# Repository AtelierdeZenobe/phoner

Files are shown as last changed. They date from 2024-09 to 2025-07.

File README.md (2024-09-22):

# Phoner [WORK IN PROGRESS]
Automate calls using sim800l module and [DFRobot Beetle_ESP32_C6](https://wiki.dfrobot.com/SKU_DFR1117_Beetle_ESP32_C6)

## Next steps
- LEDs
- 3D casing design

## Hardware setup
TODO pin diagram  
The sim800l module requires precise 3.7 voltage. [LIR2032H](https://www.eemb.com/product-11)

## Environment setup
1. Follow the [First Time Use](https://wiki.dfrobot.com/SKU_DFR1117_Beetle_ESP32_C6#target_7) to make the board available to arduino IDE
2. For serial monitor: Tools > USB CDC On Boot > Enabled

## Doc
[Sim800l arduino tutorial](https://lastminuteengineers.com/sim800l-gsm-module-arduino-tutorial/)

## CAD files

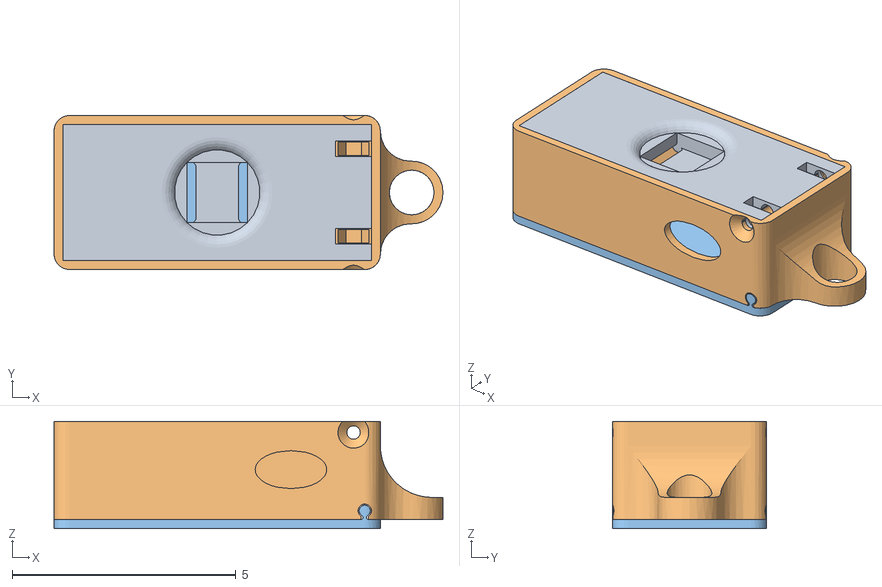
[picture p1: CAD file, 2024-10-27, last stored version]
3D/Phoner_Assembly v3.obj
8.70 x 3.45 x 2.40

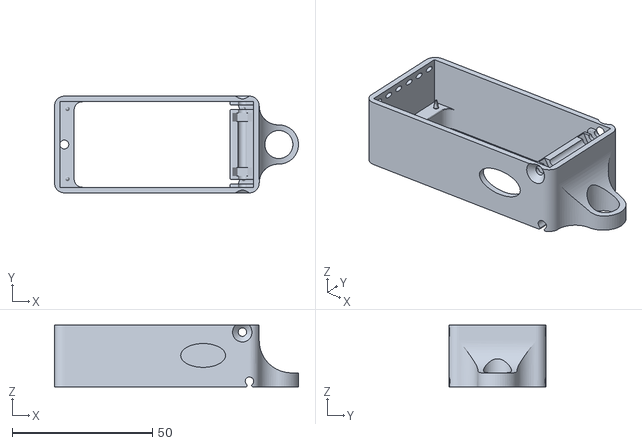
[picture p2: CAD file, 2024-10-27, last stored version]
3D/Phonerv2 v16.stl
87.0 x 34.5 x 22.0

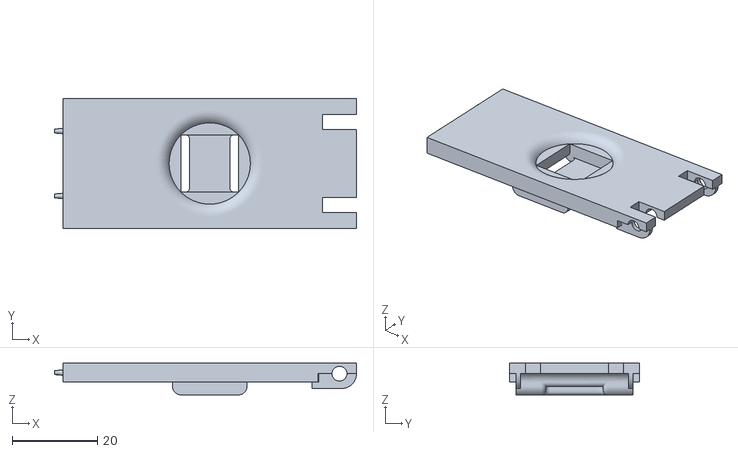
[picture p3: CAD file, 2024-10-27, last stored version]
3D/PhonerTop v6.stl
71.0 x 30.5 x 7.50

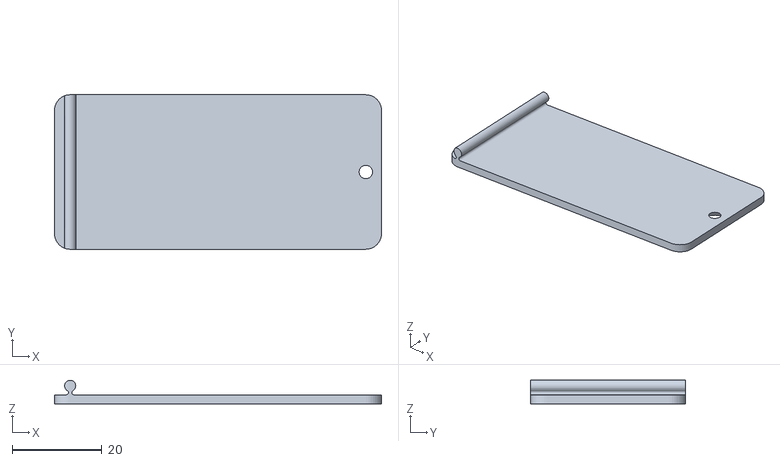
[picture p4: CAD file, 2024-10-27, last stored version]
3D/PhonerBot v4.stl
73.0 x 34.5 x 5.25

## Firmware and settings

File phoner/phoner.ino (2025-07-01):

// Tests done
// - check deepleep -> update some code, lib
// - check SIM in sleep -> if do not define CALL_FRED, that's ok !!
//                         if        define CALL_FRED, that's not ok !! I may get the call but SIM800L does not sleep after
// It's so weird, not stable from test to test
// Definetely need to check answer from SIM, retry if not the expected answer ?
// Ok it works by adjusting delays !

// RST pin is HIGH -> SIM on
// DTR pin is LOW  -> com' UART active (used for sleep mode 1)
// use Sleep mode 2
// put some delay when sending AT CFUN and CSCLK to make sure I got an OK from sim

/// Wifi
#include <WiFi.h>
#include <HTTPClient.h>
#include "info.h"
/**
Current directory should contain "info.h" defining:
struct WifiIds
{
  const char* ssid;
  const char* password;
};
constexpr WifiIds wifiIds[] =
{
  {"SSID1", "PWD1"}, // Maison parents
  {"SSID2", "PWD2"}, // Maison Loncin
};

const char* botToken, the telegram bot token (@BotFather)
const char* chat_id, the telegram chat id (@userinfobot)
*/

/// Deepsleep
#include "driver/rtc_io.h" // see https://randomnerdtutorials.com/esp32-deep-sleep-arduino-ide-wake-up-sources/
/// Sim800l comm
#include <HardwareSerial.h>

const char* PHONE_NUMBER = "+32498341934";
//const char* PHONE_NUMBER = "+32475896931";

#define USE_SIMPLE_DELAY false // set "false" for the new code for ATCommand, otherwise, set "true" to  use OLD CODE with SIMPLE DELAY
#define DELAY_WAIT_SIM 5000   
#define SHORT_DELAY_WAIT_SIM 200
#define TIMEOUT_SIM 15000 // used if USE_SIMPLE_DELAY = false

#define SLEEP_MODE 2 // 1 (using DTR pin) or 2

const int RX_PIN = 17; // ESP RX (vert)
const int TX_PIN = 16; // ESP TX (jaune)

/// Button
#define BTN_GPIO GPIO_NUM_6 // PIN 6/D12 = LP GPIO for wake up ESP32

#define LED_R GPIO_NUM_20
#define LED_G GPIO_NUM_19
const int LED_B = 0xFF; // Not connected
const int RST_GPIO = 0xFF; // Not connected
const int DTR_GPIO = 0xFF; // Not connected


HardwareSerial sim800l(1); // RX, TX pins defined above

/// Battery
const int VBAT_PIN = 0; // IO0 through a res bridge (VBAT--1M--IO0--1M//100nF--GND) as in SCH
const float VREF = 3.3;

/// On-board led
const int led = 15;

/// Setup logic
RTC_DATA_ATTR int bootCount = 0;

constexpr int MAX_WIFI_TENTATIVES = 50;

enum OPERATION_RESULT
{
  ONGOING,
  DONE,
  TIMEOUT,
  WRONG_ANSWER
};

enum class SM : int
{
  INIT = 0,
  PRESSED,
  WIFI_ATTEMPT,
  GSM_ATTEMPT,
  SUCCESS,
  FAIL
};

OPERATION_RESULT sendATCommand(HardwareSerial &serial, const char *message,const char *command, const char *expectedResponse, unsigned long timeout, bool use_delay, unsigned long delay_value);
bool ConnectToWifi();
bool setState(SM next_state, SM& current_state);

void setup()
{ 
  /// On-board led
  pinMode(led, OUTPUT);
  pinMode(LED_R, OUTPUT);
  pinMode(LED_G, OUTPUT);
  
  /// Btn
  pinMode(BTN_GPIO, INPUT);          // I made it as a pullup button, so use PULLDOWN internal resistor with rtc functions (see after call deep_sleep)
                                     // change input arg of deep sleep function esp_sleep_enable_ext1_wakeup accordingly
                                     // it seems that a pullup button is better, the wake up condition on HIGH input is better
  
  /// Battery check
  analogReadResolution(12);
  //analogSetAttenuation(ADC_6db); //ESP32-C6 datasheet: 0mv - 1900mV
  // Best to avoid edges => Going full range with "biggest error"
  analogSetAttenuation(ADC_11db);  //ESP32-C6 datasheet: 0mv - 3300 mV
  pinMode(VBAT_PIN, INPUT);

  // setup SIM800L pin digital level
  // digitalWrite(DTR_GPIO,LOW);
  // digitalWrite(RST_GPIO,HIGH);
  // delay(100);

  // Setup Serial communications
  Serial.begin(9600); // Serial monitor comm
  Serial.write("Serial initialized\n");
  Serial.write("Use Phoner Board v1.2 \n");

  // Setup sim800l module
  Serial.write("Initializing SIM800L ...");
  sim800l.begin(9600, SERIAL_8N1, RX_PIN, TX_PIN); // Works with HardwareSerial(1)
  Serial.write("done\n");
  delay(1000); // need a delay here
}

void loop()
{
  SM sm = SM::INIT;

  Serial.print("Bootcount = ");
  Serial.println(bootCount);
  // blink(500,bootCount); // for debug purpose
  // blinkForBattery();

  if(bootCount++ == 0)
  {
    start_sim800L();
    sleep_sim800L();
  }
  else
  {
    setState(SM::PRESSED, sm);
    SM next_state = ConnectToWifi() && false ? SM::WIFI_ATTEMPT : SM::GSM_ATTEMPT;
    setState(next_state, sm);
    if (sm == SM::WIFI_ATTEMPT)
    {
      HTTPClient http;
      String message = "PHONER_EMERGENCY";
      String url = String("https://api.telegram.org/bot") + botToken +
                  "/sendMessage?chat_id=" + chat_id +
                  "&text=" + message;
      http.begin(url);
      int httpCode = http.GET();
      Serial.println("HTTP Status: " + String(httpCode));
      if (httpCode != 200)
      {
        setState(SM::GSM_ATTEMPT, sm);
        String response = http.getString();
        Serial.println("Telegram Error: " + response);
      }
      else
      {
        setState(SM::SUCCESS, sm);
      }
      http.end();
    }

    if(sm == SM::GSM_ATTEMPT)
    {
      Serial.println("Could not connect to wifi, trying GSM");
      wake_up_sim800L();
      if(!call())
      {
        setState(SM::FAIL, sm);
      }
      else
      {
        setState(SM::SUCCESS, sm);
      }
      sleep_sim800L();
    }
    else
    {
      Serial.print("SM state: ");
      Serial.println(static_cast<int>(sm));
    }
  }
  delay(2000); // Easier to re-flash
  blinkForBattery(); // check battery before sleep
  sleep_esp32();
  Serial.println("This will never be printed");
}

// ------------------------------------------------------------- //
// ESP32 functions
// ------------------------------------------------------------- //
// sleep_esp32()

bool setState(SM next_state, SM& current_state)
{
  // TODO: allowed transitions
  bool result = false;
  switch(next_state)
  {
    case SM::INIT:
    {

    }
    case SM::PRESSED:
    {
      blink_RGB(500, 1, HIGH, LOW, LOW); //R
      blink_RGB(500, 1, LOW, HIGH, LOW); //G
      digitalWrite(LED_R, HIGH);
      digitalWrite(LED_G, HIGH);
      //blink_RGB(500, 1, HIGH, HIGH, LOW); //Orange ?
      result = true;
      break;
    }
    case SM::WIFI_ATTEMPT: // Orange
    {
      blink_RGB(500, 3, HIGH, HIGH, LOW); //Orange ?
      digitalWrite(LED_R, HIGH);
      digitalWrite(LED_G, HIGH);
      result = true;
      break;
    }
    case SM::GSM_ATTEMPT: // Blink red then Orange
    {
      blink_RGB(500, 3, HIGH, LOW, LOW);
      digitalWrite(LED_R, HIGH);
      digitalWrite(LED_G, HIGH);
      result = true;
      break;
    }
    case SM::SUCCESS: // GREEN
    {
      digitalWrite(LED_R, LOW);
      digitalWrite(LED_G, HIGH);
      result = true;
      break;
    }
    case SM::FAIL: // RED
    {
      digitalWrite(LED_R, HIGH);
      digitalWrite(LED_G, LOW);
      result = true;
      break;
    }
    default:
    {
      Serial.println("Default state should never happen");
    }
  }

  if(result)
  {
    Serial.print("Transition : "); Serial.print(static_cast<int>(current_state)); Serial.print(" -> "); Serial.print(static_cast<int>(next_state));
    current_state = next_state;
  }
  else
  {
    Serial.print("Incorrect transition : "); Serial.print(static_cast<int>(current_state)); Serial.print(" -> "); Serial.print(static_cast<int>(next_state));
  }
  return result;
}

bool ConnectToWifi()
{
  for (int i = 0; i < N_WIFI; ++i) 
  {
    int tentative = 0;
    const char* ssid = wifiIds[i].ssid;
    const char* password = wifiIds[i].password;

    Serial.println("Attempting to connect to wifi:");
    Serial.print("\t"); Serial.println(ssid);
    Serial.print("\t"); Serial.println(password);

    WiFi.begin(ssid, password);

    while ( (WiFi.status() != WL_CONNECTED) && (tentative++ < MAX_WIFI_TENTATIVES) )
    {
      delay(500);
      Serial.print(".");
    };
    Serial.println("");

    if(WiFi.status() == WL_CONNECTED)
    {
      Serial.println("\nWiFi connected");
      return true;
    }

    WiFi.disconnect(true);  // true = erase old config
    delay(100); // give some time to cleanly disconnect
  }
  return false;
}

void sleep_esp32()
{
  // TODO: use ANY_LOW if pull-up
  // https://randomnerdtutorials.com/esp32-deep-sleep-arduino-ide-wake-up-sources/
  esp_sleep_enable_ext1_wakeup((1ULL << BTN_GPIO), ESP_EXT1_WAKEUP_ANY_HIGH);
  // esp_sleep_enable_ext0_wakeup(BTN_GPIO, 1); // wake up if BTN pressed 
                                                // idt does not work ?? https://github.com/espressif/esp-idf/issues/11932
  rtc_gpio_pulldown_en(BTN_GPIO);  // GPIO6 is tie to GND in order to wake up in HIGH
  rtc_gpio_pullup_dis(BTN_GPIO);   // Disable PULL_UP in order to allow it to wakeup on HIGH
  // reminder : COM port is disabled, so board does show disconnected in IDE
  esp_deep_sleep_start();
}

// ------------------------------------------------------------- //
// SIM800L functions
// ------------------------------------------------------------- //
// sendATCommand()
// start_sim800L()
// reset_sim800L()
// sleep_sim800L()
// wake_up_sim800L()
// call()

// Send and check AT Commeand
// use : sendATCommand(sim800l,"Message for serial Monitor","AT","OK",DELAY_SLEEP_SIM)
OPERATION_RESULT sendATCommand(HardwareSerial &serialSIM, const char *message,const char *command, const char *expectedResponse, unsigned long timeout = TIMEOUT_SIM, bool use_delay = USE_SIMPLE_DELAY, unsigned long delay_value = DELAY_WAIT_SIM)
{
  OPERATION_RESULT result = OPERATION_RESULT::ONGOING;
  serialSIM.println(command);
  if (use_delay)
  {
    updateSerial();
    delay(delay_value);
    result = OPERATION_RESULT::DONE;
  }
  else
  {
    unsigned long startTime = millis();
    unsigned long elapsedTime = 0;
    String response = "";

    while ( result==OPERATION_RESULT::ONGOING )
    {
      elapsedTime =  millis() - startTime;
      if( elapsedTime > timeout )
      {
        result = OPERATION_RESULT::TIMEOUT;
      }
      while (serialSIM.available() && result==OPERATION_RESULT::ONGOING)
      {
        char c = serialSIM.read();
        response += c;
        // Vérifiez si la réponse attendue est contenue
        if (response.indexOf(expectedResponse) != -1)
        {
          result = OPERATION_RESULT::DONE;
        }
      }
      //delay(1); // it is ok because baudrate is set to 9600x
    }

    switch(result)
    {
      case OPERATION_RESULT::DONE:
      {
        Serial.println(String(message) + " Command " + String(command) + " success");
        Serial.println(response);
        Serial.println(elapsedTime);
        break;
      }
      case OPERATION_RESULT::ONGOING:
      {
        Serial.println(String(message) + " Command " + String(command) + " ONGOING");
        Serial.println(response);
        break;
      }
      case OPERATION_RESULT::TIMEOUT:
      {
        Serial.println(String(message) + " Command " + String(command) + " TIMEOUT");
        Serial.println(response);
        Serial.println(elapsedTime);
        break;
      }
      case OPERATION_RESULT::WRONG_ANSWER:
      {
        Serial.println(String(message) + " Command " + String(command) + " WRONG ANSWER");
        Serial.println(response);
        break;
      }
      default:
      {
        Serial.println(String(message) + " Command " + String(command) + " DEFAULT");
        Serial.println(response);
        break;
      }
    }     
    return result;
  }
}

void start_sim800L()
{
  wake_up_sim800L();
  sendATCommand(sim800l,"Starting handshake...","AT","OK"); // Starting handshake
  sendATCommand(sim800l,"Signal quality test...","AT+CSQ","OK"); //Signal quality test, value range is 0-31 , 31 is the best
  sendATCommand(sim800l,"Reading SIM information...","AT+CCID","OK"); //Read SIM information to confirm whether the SIM is plugged
  //sendATCommand(sim800l,"Selecting mobile operator...","AT+COPS=0,2","OK",TIMEOUT_SIM,USE_SIMPLE_DELAY,SHORT_DELAY_WAIT_SIM); // select the mobile network operator| AT+COPS=<mode>(0 for auto),<format>(2 for numeric),<oper>,<AcT>
  // there is an error here, is it worth sending this command ? So comment it
  sendATCommand(sim800l,"Checking network status...","AT+CREG?","OK"); //check the network registration status. Will answer +CREG: <n>,<stat>
  sendATCommand(sim800l,"Querying battery status...","AT+CBC","OK"); // Querry battery status
  sendATCommand(sim800l,"Enabling CLC...","AT+CLCC=0","OK"); // Don't send AT+CLCC async
}
void reset_sim800L()
{
  digitalWrite(RST_GPIO,HIGH);
  delay(200);
  digitalWrite(RST_GPIO,LOW); // put this pin LOW for (at least) 100ms for a hard reset
  delay(200);
  digitalWrite(RST_GPIO,HIGH);
  delay(200);
}
// Sleep mode 2 : https://www.raviyp.com/223-sim900-sim800-sleep-mode-at-commands/
// RF OFF : datasheet page 26, section 4.3
void sleep_sim800L()
{
  Serial.println("");
  Serial.println("Going to sleep now");
  while(sendATCommand(sim800l,"Set RF off","AT+CFUN=4","OK") != OPERATION_RESULT::DONE){
    delay(SHORT_DELAY_WAIT_SIM);
  } // wait for the OK response, it may take a while to get the answer;
  delay(DELAY_WAIT_SIM); // should reply within 10 sec max according to AT CFUN page 96
  if (SLEEP_MODE == 1)
  {
    while(sendATCommand(sim800l,"Set sleep mode 1","AT+CSCLK=1","OK") != OPERATION_RESULT::DONE){
      delay(SHORT_DELAY_WAIT_SIM);
    } // wait for the OK response, it may take a while to get the answer;
    delay(100);
    digitalWrite(DTR_GPIO,HIGH); // put high for sleep mode
    delay(100);
  }
  else if (SLEEP_MODE == 2)
  {
    while(sendATCommand(sim800l,"Set sleep mode 2","AT+CSCLK=2","OK") != OPERATION_RESULT::DONE){
      delay(SHORT_DELAY_WAIT_SIM);
    } // wait for the OK response, it may take a while to get the answer;
    delay(DELAY_WAIT_SIM*2); // wait for at least 5s without UART, on air or IO INTR
  }
  else 
  {
    // no SLEEP mode
  }
}

void wake_up_sim800L()
{
  Serial.println("Wake up SIM800L");
  sim800l.println("AT"); // dummy data, wait no response, so do not use sendATCommand
  delay(200); // datasheet AT command page 153, note 2 : apply a delay of (at least) 100ms between dummy/waking data and AT command
  Serial.println("Disable sleep mode");
  if (SLEEP_MODE == 1)
  {
    digitalWrite(DTR_GPIO,LOW);
    delay(100); // UART should be ready after 50ms
  }
  else if (SLEEP_MODE == 2)
  {
    sendATCommand(sim800l,"Wake up module SIM","AT+CSCLK=0","OK");
    delay(DELAY_WAIT_SIM); // wait for at least 5s without UART, on air or IO INTR
  }
  else 
  {
    // no SLEEP mode
  }
  sendATCommand(sim800l,"Wake up RF","AT+CFUN=1","OK");
  delay(DELAY_WAIT_SIM); // wait for a few seconds to let RF be ready
}

bool call()
{
  Serial.println("Who do you call ?");
  // CALL

  OPERATION_RESULT call_success;
  OPERATION_RESULT hang_success;

  if (strlen(PHONE_NUMBER) >= 9)
  {
    call_success=sendATCommand(sim800l,"Calling...",(String("ATD") + PHONE_NUMBER + ";").c_str(),"OK",TIMEOUT_SIM,USE_SIMPLE_DELAY,SHORT_DELAY_WAIT_SIM);
  }
  else
  {
    Serial.write("Size of phone number < 9 => Fake call...\n");
    call_success=OPERATION_RESULT::DONE; 
  }

  Serial.write("Waiting for answer\n");
  long timeout = millis() + 20*1000;
  String answer;
  while (millis() < timeout)
  {
    auto callStatus = sendATCommand(sim800l, "Checking call status...", "AT+CLCC", "+CLCC: 1,0,0,0,0,", 500);
    if(callStatus == OPERATION_RESULT::DONE)
    {
      Serial.println("Connected");
    }
    else
    {
      Serial.println(".");
    }
    /*
    if (sim800l.available())
    {
      
      
      char c = sim800l.read();
      //Serial.print(c);  // Forward response to serial monitor
      answer += c;
      if(c == '\n')
      {
        //Serial.print("EOL detected. Checking answer\n");
        Serial.print(answer);
        if(answer.substring(0,5)=="+CLCC")
        {
          Serial.print("CLCC detected\n");
        }
        answer = "";
      }
      
    }
    */
  }
  /*
  for (int n_loop=0;n_loop<20;n_loop++)
  {
    delay(1000); // wait
    Serial.print(".");
  }
  */
  Serial.println("");
  // better to wait for a reply or a connection beforing hanging up ??
  hang_success=sendATCommand(sim800l,"Hanging up...","ATH","OK");
  // here, check if call and/or hanging are true
  if ( (hang_success != OPERATION_RESULT::DONE) && (call_success != OPERATION_RESULT::DONE)) // a problem occurred -> blink or restart call ?
    return false;
  else
    return true;
}

// ------------------------------------------------------------- //
// Misc functions
// ------------------------------------------------------------- //

void updateSerial()
{
  delay(500); // wait for any incoming data
  while (Serial.available()) 
  {
    sim800l.write(Serial.read());//Forward what Serial received to Software Serial Port
  }
  while(sim800l.available()) 
  {
    Serial.write(sim800l.read());//Forward what Software Serial received to Serial Port
  }
}

// blink N times the LED with a period of 2*millis
void blink(const int millis,int N)
{
  for (int i=0;i<N;i++)
  {
    digitalWrite(led, LOW);
    delay(millis);
    digitalWrite(led, HIGH);
    delay(millis);
    digitalWrite(led, LOW);
  }
  
}

// blink N times the LED with a period of 2*millis
void blink_RGB(const int millis,int N, unsigned char state_LEDR, unsigned char state_LEDG, unsigned char state_LEDB)
{
  for (int i=0;i<N;i++)
  {
    digitalWrite(LED_R, LOW);
    digitalWrite(LED_G, LOW);
    digitalWrite(LED_B, LOW);
    
    delay(millis);
    digitalWrite(LED_R, state_LEDR);
    digitalWrite(LED_G, state_LEDG);
    digitalWrite(LED_B, state_LEDB);
    
    delay(millis);
    digitalWrite(LED_R, LOW);
    digitalWrite(LED_G, LOW);
    digitalWrite(LED_B, LOW);
  }
}

void blinkForBattery()
{
  //TODO
  // ESP32 ADCs are known for non-linearity and compression. => Going for a calibration under voltage threshold, measuring via external PSU.
  // Measure around critical threshold voltage: ~1.8V measured (3.6V). And create a calibration curve
  
  Serial.println("Reading battery:");
  // ADC is 12 bits precision -> 0 to 4095
  // int rawValue = analogRead(VBAT_PIN); // Voltage from ADC [0;4095]
  int NMES = 4; // no more than 16
  unsigned int rawValue=0;
  for(int i=0;i<NMES;i++)
  {
    rawValue+=analogRead(VBAT_PIN); // Voltage from ADC [0;4095]
    delay(1);
  }
  rawValue = rawValue/NMES; // average of a bunch of measures
  Serial.print("Raw value:");
  Serial.println(rawValue);
  // Vref is 3.3V so 4095 correspond to 3.3V.
  // The voltage mesurement is actually VBAT/2
  float voltage = 2 * (rawValue * VREF) / 4095.0; // Convert to actual volts (max 3.3V)
  //voltage *= (4.12/3.38); // strange ratio , read 3.38V on analog input (in serial monitor) and 4.12V on multimeter

  Serial.print("Battery Voltage: ");
  Serial.print(voltage); // VBAT
  Serial.println(" V");

  int n_blinks = (rawValue-1600)/100;
  Serial.print("Blinking ");
  Serial.print(n_blinks);
  Serial.println(" times");
  blink(500, n_blinks); //
  // use the RGD LED instead
  // Green  : >50%    of [3.5-4.2] : voltage>3.85 V
  // Yellow : 25-50%  of [3.5-4.2] : 3.675 V <= voltage <= 3.85 V 
  // Red    : <25%    of [3.5-4.2] : voltage < 3.675 V

  // Theorical minimal voltage is 3.4V but the batery measurement seems lower than actual battery ? TBC
  // That's why a wierd ratio is used to correct the voltage measurement, i.e. 4.12/3.38
  /*
  if (voltage > 3.85){
    blink_RGB(500,3,LOW,HIGH,LOW);
    // blink(500,voltage_deca);
  }
  else{
    if ((3.675 <= voltage) && (3.85 >= voltage))
      blink_RGB(300,5,HIGH,HIGH,LOW);
      // blink(300,voltage_deca*2);
    else
      // blink(100,voltage_deca*3);
      blink_RGB(100,15,HIGH,LOW,LOW);
  }
  */
}

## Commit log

2024-08-16 Button press for call
2024-09-22 Add voltage info
2024-10-12 Sleep mode with SIM on stage !
2024-10-27 stl files
    [PhonerBot v4.stl, PhonerTop v6.stl, Phonerv2 v16.stl]
2024-10-27 add 3D object
    [Phoner_Assembly v3.obj]
2024-10-27 3D folder
    [PhonerBot v4.stl, PhonerTop v6.stl, Phoner_Assembly v3.obj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]
2024-12-30 Add board versions, add SIMPLE DELAY in ATCommand, adjust delays
2025-04-13 Default to V2 with faulty led
2025-04-13 Remove 3d folder
    [PhonerBot v4.stl, PhonerTop v6.stl, Phoner_Assembly v3.obj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]
2025-04-19 update file location for arduino ide
2025-04-19 Error code and timeout increase
    [phoner.ino]
2025-05-04 board v2 only + blink_battery + loop to sleep
2025-05-26 LED OK, CALL NOK
2025-05-27 Sleep + commands + LED functional with correct pins
    [phoner.ino]
2025-06-24 Attempt all wifis then call, led color code
2025-06-24 Some comments on battery voltage
